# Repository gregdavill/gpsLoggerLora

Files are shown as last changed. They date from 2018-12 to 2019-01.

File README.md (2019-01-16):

# gpsLogger

	Project Stage: Firmware Devlopment
	v0.1a Prototyp Assembled
	Current Bugs:
	 * FLASH footprint wrong (fix in v0.2)
	 * Change BOM MCP73812 (CE pin) to MCP73832 (STATUS pin)
	 * Small changes to RF paths
	 * Update solderpaste apertures on X2SON parts (too much paste)
	 * Needs more test-points 
	 * LED colours B/G swapped

A basic portable GPS logger with LoRa wireless based on Microchip ATSAMR34
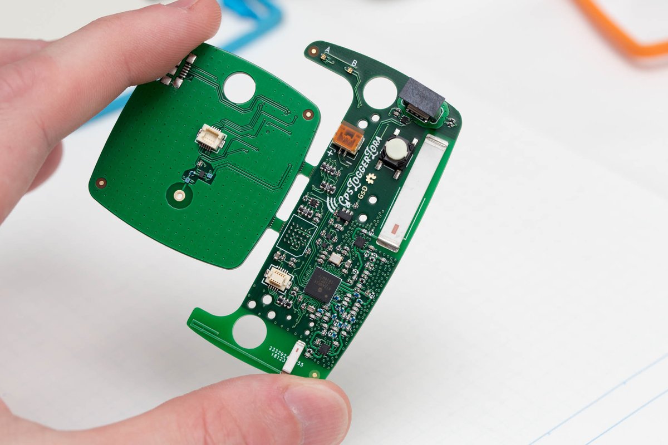
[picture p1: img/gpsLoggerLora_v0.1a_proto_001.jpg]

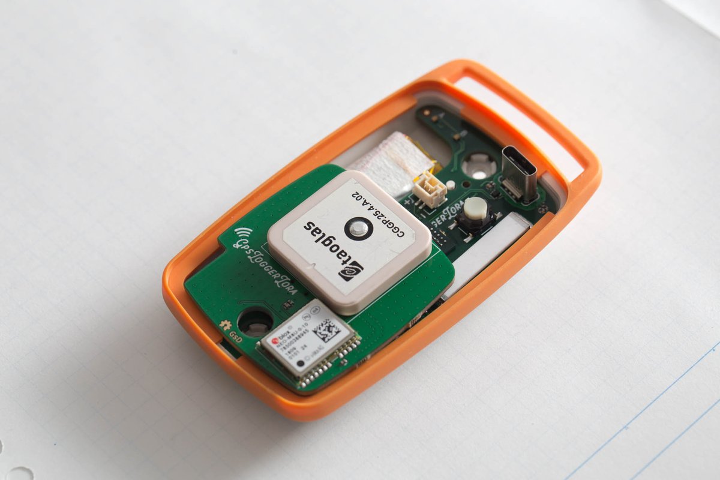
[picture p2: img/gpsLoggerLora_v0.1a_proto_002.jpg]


v0.1a PCB has been designed to accomidate both 433MHz and 868/915MHz bands. However support may be dropped for 433MHz in the future.

The PCB is design to fit in an existing enclosure used by a previous GPS datalogger.
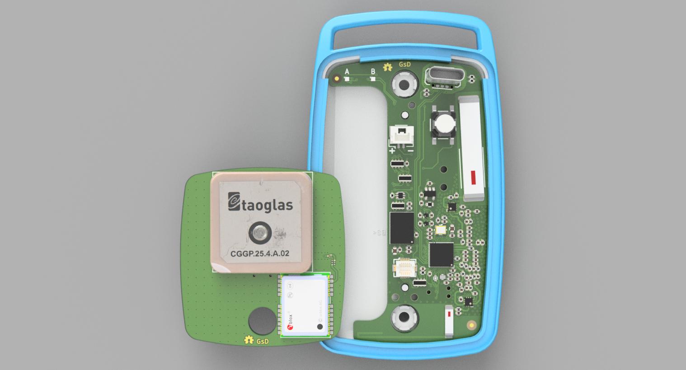
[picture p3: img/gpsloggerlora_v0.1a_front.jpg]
Enclosure


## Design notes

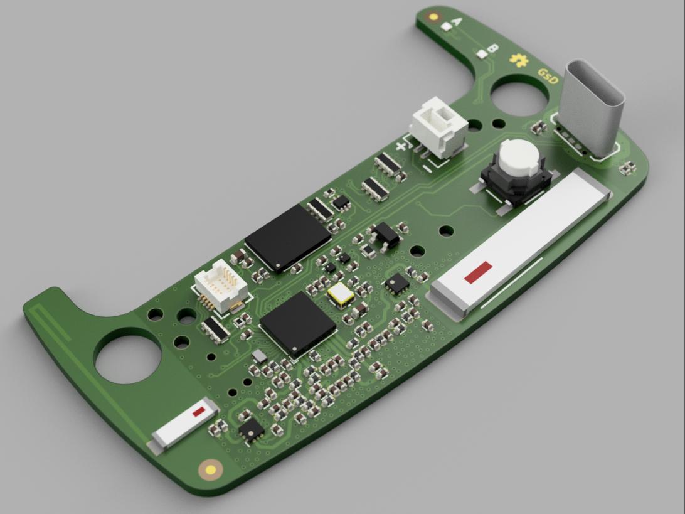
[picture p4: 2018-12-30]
img/gpsloggerlora_v0.1a_pcb.jpg

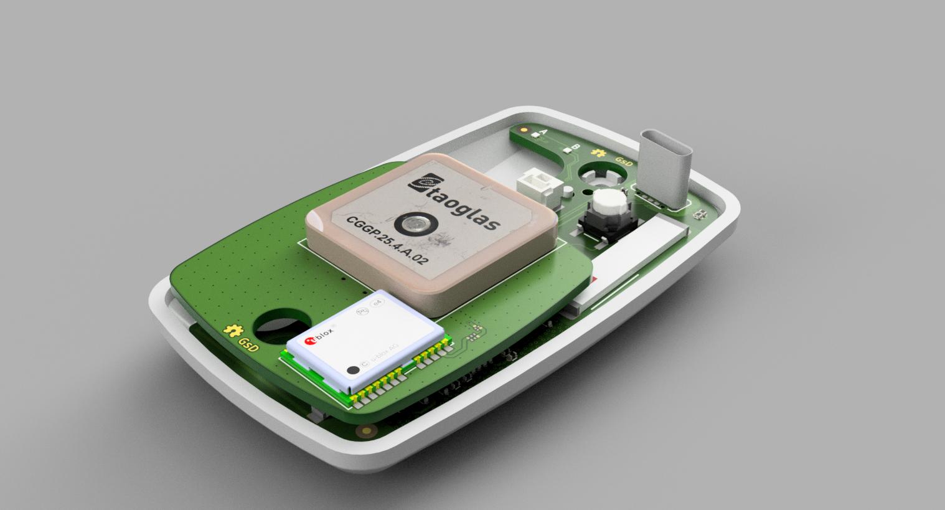
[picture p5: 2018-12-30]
img/gpsloggerlora_v0.1a_side.jpg

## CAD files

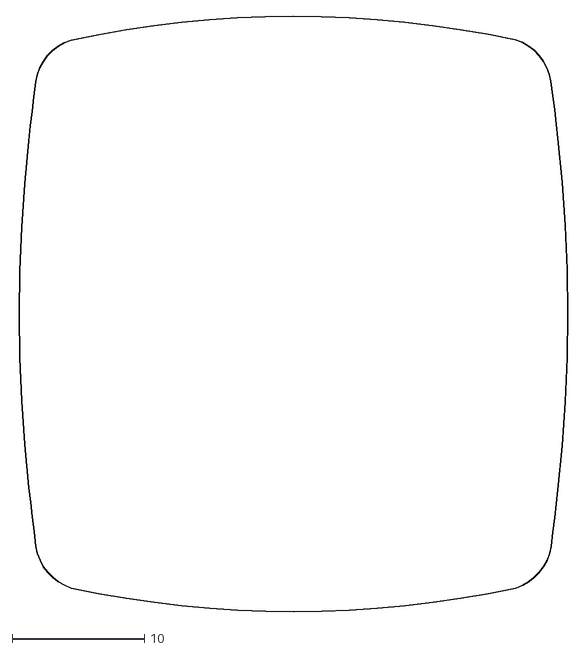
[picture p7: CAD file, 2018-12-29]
hardware/gps-v0.1a/ref/outline.dxf
41.9 x 45.0

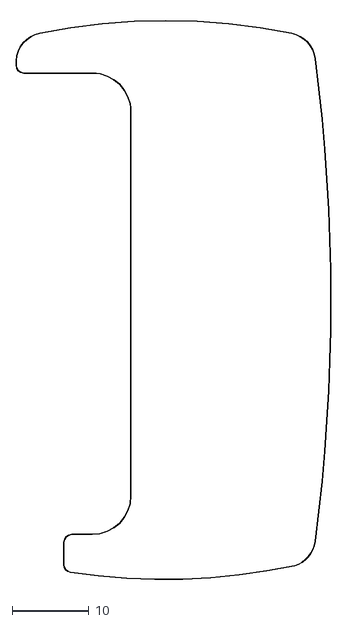
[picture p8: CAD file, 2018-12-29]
hardware/v0.1b/ref/outline.dxf
41.6 x 73.8

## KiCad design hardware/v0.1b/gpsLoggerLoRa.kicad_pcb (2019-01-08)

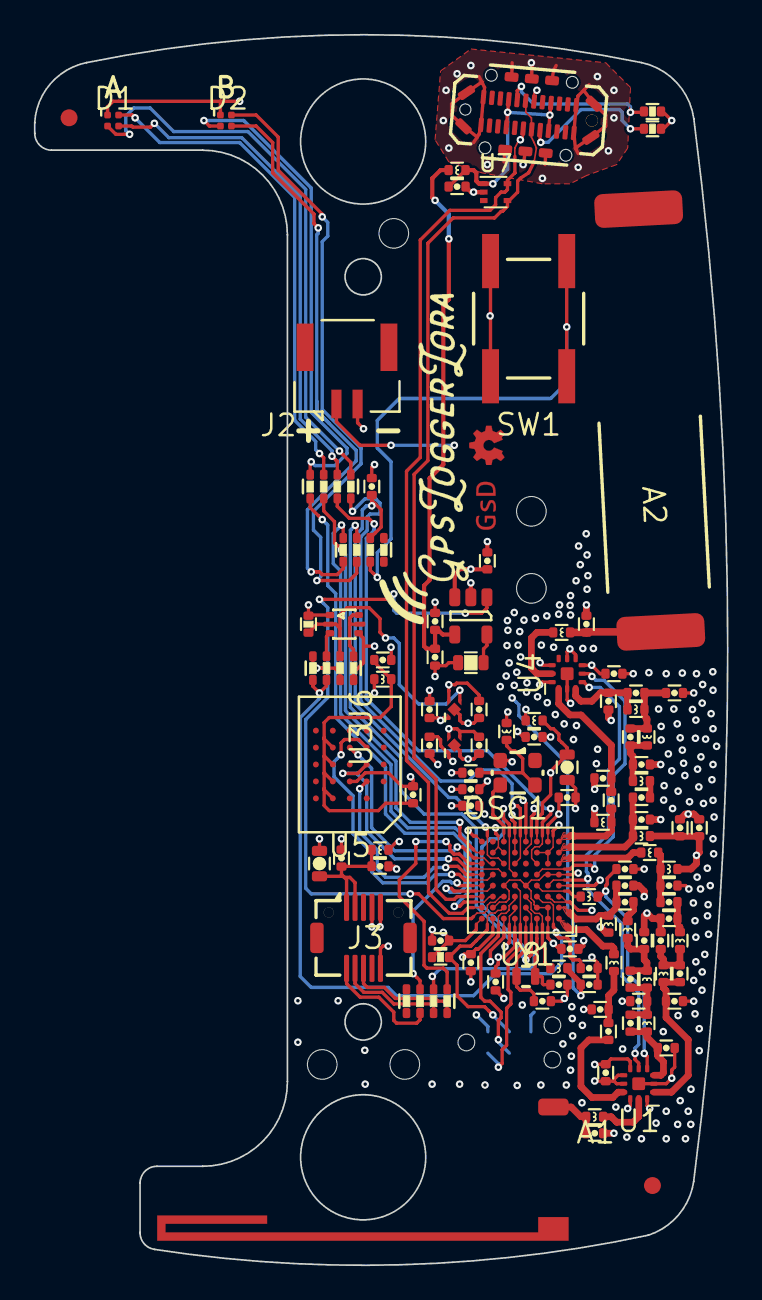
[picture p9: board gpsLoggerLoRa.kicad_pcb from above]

Board: 4 copper layers, 40.9 x 72.7 mm, 111 parts (1 on the bottom side), 83 nets.

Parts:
A1: pkl_ANTENNA; 0900AT43A0070 - 900MHz Wide band ISM Chip Antenna
A2: pkl_ANTENNA; 0433AT62A0020 - 433MHz 25x5x1mm chip antenna
C1, C2, C3, C6, C11, C15, C32, C44, C47, C48, C52, C54, C55, C56: 100nF; C_0402
C4, C22, C27, C57, C59: 4.7pF; C_0402
C5, C21, C28, C29, C35, C39: DNP; C_0402
C7, C8, C18, C36, C40: 3.9pF; C_0402
C9: 10n; C_0402
C10, C13, C34: 22pF; C_0402
C12, C33, C38, C51: 18pF; C_0402
C14, C16, C17, C43, C53, C58: 1uF; C_0402
C19: 0R; C_0402
C20: 8.2pF; C_0402
C23: 4.7nF; C_0402
C24, C26: 6.8pF; C_0402
C25: 2.7pF; C_0402
C30: 33nF; C_0402
C31, C42: 1nF; C_0402
C37: 5.6pF; C_0402
C41: 3.3pF; C_0402
C45, C46: 10uF; C_0603
C49, C50: 10pF; C_0402
D1, D2: LED_ARGB; 0404LED_RGB
J1: USB_C_Receptacle; usbc_vert_10132328
J2: JST GH; BM02B-GHS-TBT
J3: DF12 - 10P; DF12(3.0)-10DP-0.5V(86)
J4: CTX TAG Connect; TC2030-NL_SMALL
L1: 18nH; L_0402
L2, L10, L22: 2.2nH; L_0402
L3, L4: 33nH; L_0402
L6: 82nH; L_0402
L7: 15nH; L_0402
L8: 12nH; L_0402
L9: 0R; L_0402
L11, L12: 11nH; L_0402
L13, L14, L15, L16, L23, L24: 10nH; L_0402
L17, L18, L19, L20, L21: 1k; L_0402
OSC1: TYETBCSANF-32.000000; Oscilator_2.5x2.0
Q1: FG6943010R; SOT-666
R1: 1k; R_0603
R2, R3, R4: 100R; R_Array_Concave_4x0603
R5, R7: 10k; R_0402
R6: 47k; R_Array_Concave_4x0603
R8, R9: 5.1k; R_0402
SW1: SW_Push; EVQ_switch
U1, U4: SKY13373; QFN-12-1EP_3x3mm_P0.5mm_EP1.65x1.65mm
U2: MCP73832; SOT-23-5
U3, U6: NCP167; X2SON_4_1.0x1.0mm
U5: MT25QL256ABA8E12; T-PBGA-24_6.0x8.0mm_Layout5x5_P1.0mm
U7: NUP2114; SOT-553
U8: ATSAMR34J18B; TFBGA-64_6.0x6.0mm_Layout8x8_P0.65mm
Y1: 32.768kHz; ABS05_32.768KHz Crystal

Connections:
+3V3: C2.2, C3.2, C6.2, C17.1, J3.10, J4.1, L18.1, R7.1, U3.1, U8.A7, U8.A8, U8.G4, U8.H8
/SAMR34/AUX_PWR_EN: C27.2, L24.1, Q1.2, R5.1, R6.6, U6.3
/SAMR34/BAND_SEL: C22.2, L23.1, U1.4
/SAMR34/BATTERY_VOLTAGE: C57.2, R6.1, R6.3, U8.C3
/SAMR34/CLK: J4.4, U8.C5
/SAMR34/DIO: J4.2, U8.D5
/SAMR34/FLASH_CLK: U5.B2, U8.E8
/SAMR34/FLASH_CS#: U5.C2, U8.E6
/SAMR34/GPS_PPS: R4.8, U8.F8
/SAMR34/GPS_RX: R4.6, U8.E5
/SAMR34/GPS_TX: R4.4, U8.D8
/SAMR34/LED_A_BLUE: R3.6, U8.G8
/SAMR34/LED_A_GREEN: R3.4, U8.F3
/SAMR34/LED_A_RED: R3.2, U8.F5
/SAMR34/LED_B_BLUE: R2.4, U8.B4
/SAMR34/LED_B_GREEN: R2.2, U8.C7
/SAMR34/LED_B_RED: R3.8, U8.D7
/SAMR34/PA_BOOST: L2.1, U8.F1
/SAMR34/PP3V3_AUX: C53.1, D1.1, D2.1, L19.2, L20.2, L21.2, U6.1
/SAMR34/RESET: J4.3, R7.2, U8.B6
/SAMR34/RFI_HF: L11.1, U8.A1
/SAMR34/RFI_LF: C59.1, L1.2, U8.H1
/SAMR34/RFO_HF: C7.2, C10.2, L3.1, U8.B1
/SAMR34/RFO_LF: C4.2, C19.2, L6.2, U8.G1
/SAMR34/RX\TX: U1.5, U4.4, U8.D2
/SAMR34/SHDN: U4.5, U8.E3
/SAMR34/USB_DATA_N: J1.A7, J1.B7, U7.5, U8.B8
/SAMR34/USB_DATA_P: J1.A6, J1.B6, U7.4, U8.C8
/SAMR34/USER_BUTTON: C56.1, R2.6, U8.F6
/SAMR34/VR_PA: C21.2, C23.2, L3.2, L4.1, L6.1, U8.D1
/USB/CHARGE_STAT: U2.1, U8.C6
/USB/VBAT: C15.1, C16.1, C52.1, J2.1, Q1.4, R6.7, U2.3, U3.3, U3.4, U6.4
/memio/DQ0: U5.D3, U8.F7
/memio/DQ1: U5.D2, U8.E7
AVDD: C1.2, C31.1, C42.1, C45.2, L18.2, U1.6, U4.6, U8.C1, U8.C2, U8.H3
GND: C1.1, C2.1, C3.1, C4.1, C5.1, C6.1, C7.1, C8.1, C9.2, C11.2, C13.1, C14.2, C15.2, C16.2, C17.2, C18.1, C20.1, C21.1, C22.1, C23.1, C24.1, C26.1, C27.1, C29.1, C30.2, C31.2, C32.2, C33.1, C36.1, C37.1, C40.1, C41.1, C42.2, C43.2, C44.2, C45.1, C46.2, C47.1, C48.1, C49.1, C50.2, C51.1, C52.2, C53.2, C54.2, C55.2, C56.2, C57.1, C58.1, J1.A1, J1.A12, J1.B1, J1.B12, J1.S1, J2.2, J3.7, J3.9, J4.5, L1.1, OSC1.2, Q1.1, R1.2, R5.2, R6.2, R6.5, R8.2, R9.2, SW1.2, U1.2, U1.7, U1.8, U1.10, U1.12, U1.13, U2.2, U3.2, U4.2, U4.7, U4.8, U4.10, U4.12, U4.13, U5.B3, U6.2, U7.2, U8.A2, U8.B2, U8.B3, U8.B5, U8.B7, U8.D4, U8.D6, U8.E1, U8.E2, U8.F2, U8.G2, U8.G3, U8.G5, U8.G6, U8.G7, U8.H5
unnamed: A1.1, C51.2, L22.2
unnamed: A2.1, C33.2, L10.2
unnamed: C5.2, C59.2, U4.1
unnamed: C9.1, J1.A4, J1.A9, J1.B4, J1.B9, L17.2, U7.1
unnamed: C10.1, L12.1
unnamed: C11.1, C14.1, L17.1, U2.4
unnamed: C8.2, C12.1, L2.2, L4.2
unnamed: C12.2, C18.2, L13.1
unnamed: C13.2, C34.2, L11.2
unnamed: C19.1, L7.1
unnamed: C20.2, C35.1, L12.2, L14.1
unnamed: C24.2, C25.1, L7.2, L8.1
unnamed: C25.2, C26.2, C28.1, L8.2, L9.1
unnamed: C28.2, C29.2, L9.2, U4.3
unnamed: C30.1, C32.1, U8.H2
unnamed: C34.1, U1.9
unnamed: C35.2, C37.2, C39.1, L14.2, L16.1
unnamed: C36.2, C38.1, L13.2, L15.1
unnamed: C38.2, C40.2, L15.2, U1.1
unnamed: C39.2, C41.2, L16.2, U1.3
unnamed: C43.1, C44.1, L19.1, U5.A4, U5.B4, U5.C4, U5.D4
unnamed: C46.1, C54.1, C55.1, J3.1, J3.3, L20.1
unnamed: C47.2, U8.H4
unnamed: C48.2, L21.1, OSC1.4
unnamed: C49.2, U8.A4, Y1.1
unnamed: C50.1, U8.A3, Y1.2
unnamed: C58.2, U8.A5
unnamed: D1.2, R3.1
unnamed: D1.3, R3.3
unnamed: D1.4, R3.5
unnamed: D2.2, R3.7
unnamed: D2.3, R2.1
unnamed: D2.4, R2.3
unnamed: J1.A5, R9.1
unnamed: J1.B5, R8.1
unnamed: J3.2, R4.3
unnamed: J3.4, R4.5
unnamed: J3.6, R4.7
unnamed: L10.1, U4.11
unnamed: L22.1, U1.11
unnamed: L23.2, U8.D3
unnamed: L24.2, U8.C4
unnamed: OSC1.3, U8.H6
unnamed: Q1.3, R6.4
unnamed: Q1.5, Q1.6, R6.8
unnamed: R1.1, U2.5
unnamed: R2.5, SW1.1

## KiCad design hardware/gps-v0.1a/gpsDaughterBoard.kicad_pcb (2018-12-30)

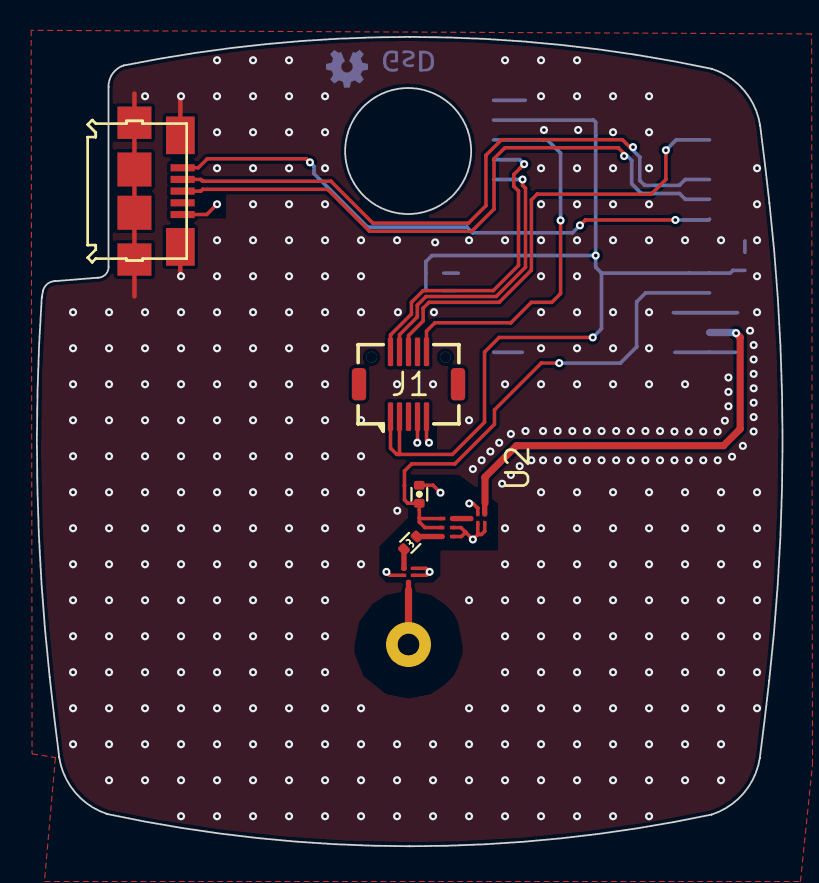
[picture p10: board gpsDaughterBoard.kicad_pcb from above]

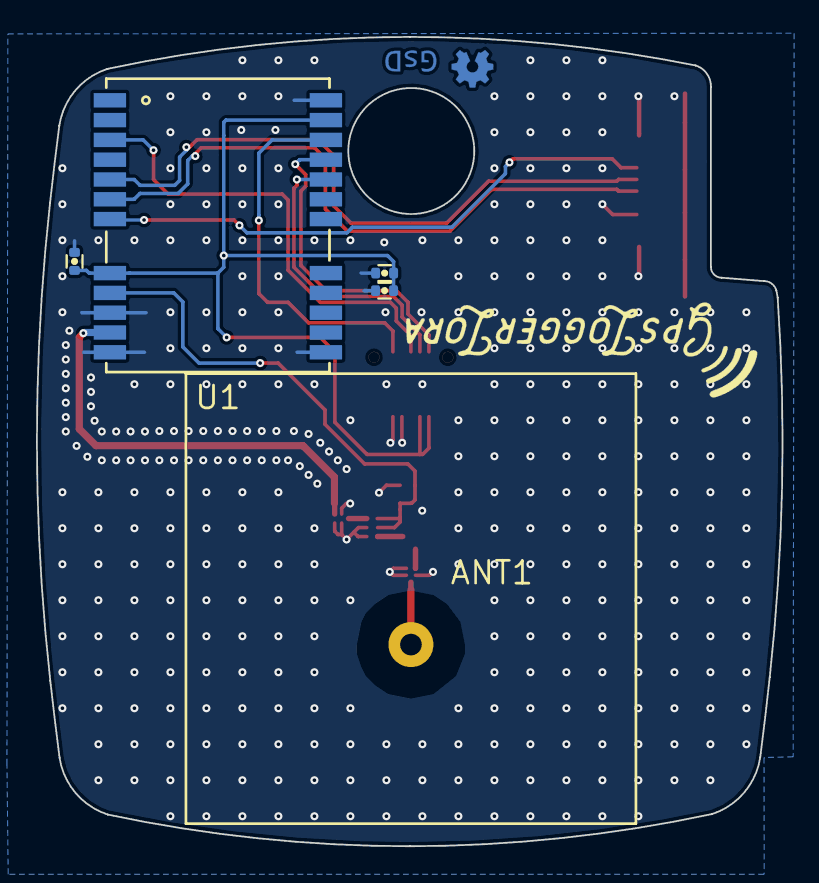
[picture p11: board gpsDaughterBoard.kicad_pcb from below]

Board: 4 copper layers, 41.4 x 45.0 mm, 12 parts (5 on the bottom side), 15 nets.

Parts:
ANT1: pkl_PATCH_ANTENNA; GPS_ANT
C1: 10nF; C_0402
C2, C3: 100nF; C_0402
C4: 1nF; C_0402
FLT1, FLT2: SF1186G; SAW-5
J1: JST DF12 10P; DF12(3.0)-10DS-0.5V(86)
J2: USB_OTG; Connector_USB_Micro_B_SMD
L1: 5.6nH; L_0402
U1: NEO_M8; NEO-M8
U2: BGU7007; XSON6

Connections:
+3V3: C1.1, C2.1, C3.1, J1.1, J1.3, U1.8, U1.23
/DATA_N: J2.2, U1.5
/DATA_P: J2.3, U1.6
/PPS: J1.6, U1.3
/RX: J1.4, U1.20
/TX: J1.2, U1.21
GND: C1.2, C2.2, C3.2, C4.2, FLT1.2, FLT1.4, FLT1.5, FLT2.2, FLT2.4, FLT2.5, J1.7, J1.9, J2.5, J2.GND, U1.10, U1.12, U1.13, U1.24, U2.4, U2.5
unnamed: ANT1.1, FLT2.1
unnamed: C4.1, U1.9, U2.1, U2.2
unnamed: FLT1.1, U2.6
unnamed: FLT1.3, U1.11
unnamed: FLT2.3, L1.2
unnamed: J1.10, U1.22
unnamed: J2.1, U1.7
unnamed: L1.1, U2.3

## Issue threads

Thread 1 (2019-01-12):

FLASH footprint is wrong

gregdavill, 2019-01-12:
The FLASH footprint on v0.1a hardware is wrong.

Coordinates for X/Y are swapped. Such that A3 should actually be C1, (A=1, 3=C) If that makes sense.

I had taken a footprint from my Boson project, that had the same error. I had thought I had updated the library footprint, but turned out I had only ever updated it in at the PCB level for that project.

The fix on v0.1a hardware is a mod-wire fix to re-map the BGA pins correctly.
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

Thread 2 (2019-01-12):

Incorrect BOM entry MCP73812

gregdavill, 2019-01-12:
The BOM for v0.1a lists a MCP73812, this is also present in the Schematic (As that's where the BOM data originates). However the schematic describes the functionality of the MCP73832.

Both chips are the same footprint and are equal except for the function of pin 1.
 * MCP73812 - Pin 1: CE (Chip Enable)
 * MCP73832 - Pin 1: STAT (Open Drain Charge Indicator)

v0.1a should be reworked with the correct part.

Chip enable is not particularly useful for this device. Charge status is much more useful.

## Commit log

2018-12-27 Fixing up some errors after shuffle of libraries.
    [SAMR34.sch, gpsLoggerLoRa.sch]
2018-12-28 Changed USB connector. Updated board outline. Updates to footprints to use 3d models. Add FLASH memory.
    [SAMR34.sch, USB.sch, gpsLoggerLoRa.kicad_pcb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]
2018-12-28 First pass schematic done. Begin routing main board.
    [SAMR34.sch, USB.sch, gpsLoggerLoRa.kicad_pcb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]
2018-12-28 First pass routing complete.
    [gpsLoggerLoRa.kicad_pcb]
2018-12-29 Re-assigned IO pins. Added some extra filter as per Hardware guidelines.
    [SAMR34.sch, USB.sch, gpsLoggerLoRa.kicad_pcb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]
2018-12-29 Add outline dxf and lib-cache.
    [outline.dxf]
2018-12-29 Add initial version of gpsDaughterBoard.
    [gpsDaughterBoard.kicad_pcb, gpsDaughterBoard.sch, outline.dxf]
2018-12-29 Small updates to the layout. Fixed up power planes. Passed DRC
    [SAMR34.sch, USB.sch, gpsLoggerLoRa.kicad_pcb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]
2018-12-29 Added Vcore Cap. Missing from Microchips app note reference schematic
    [SAMR34.sch, gpsLoggerLoRa.kicad_pcb]
2018-12-29 First Pass routing GPS board
    [gpsDaughterBoard.kicad_pcb, gpsDaughterBoard.sch]
2018-12-29 Added TVS diode to USB input.
    [USB.sch, gpsLoggerLoRa.kicad_pcb]
2018-12-29 Checked RF filters with reference schematics. Updated all Part Numbers for BOM.
    [SAMR34.sch, USB.sch, gpsLoggerLoRa.kicad_pcb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]
2018-12-29 Update LED resistors to 330R to limit max current to 5mA
    [memio.sch]
2018-12-29 Added BOM part numbers to GPS PCB.
    [gpsDaughterBoard.sch]
2018-12-30 Finished routing the daughterboard.
    [gpsDaughterBoard.kicad_pcb]
2018-12-30 Fixed a DRC error in the GPS PCB. Small layout change to include a logo/product name on the PCB. Created a prototype 'panel' with both PCB attached for production.
    [gpsDaughterBoard.kicad_pcb, gpsLoggerLoRa.kicad_pcb, gpsLoggerLoRa_w_gps_panel.kicad_pcb]
2018-12-30 Updated GPS pcb with impoved RF path, and potetially easier to solder filters. Added USB connector to GPS pcb for debugging ublox.
    [gpsDaughterBoard.kicad_pcb, gpsDaughterBoard.sch]
2018-12-30 Re-do panel with new changes from GPS PCB.
    [gpsLoggerLoRa_w_gps_panel.kicad_pcb]
2019-01-08 Add new hardware version v1.0b
    [SAMR34.sch, USB.sch, gpsLoggerLoRa.kicad_pcb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]
2019-01-08 Fix to FLASH footprint.
    [gpsLoggerLoRa.kicad_pcb]
2019-01-12 Update Readme. Add photos from prototype. Document some Errata for v0.2
